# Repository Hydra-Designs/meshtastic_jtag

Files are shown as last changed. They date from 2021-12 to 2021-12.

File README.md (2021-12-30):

# meshtastic_jtag
An easy to assemble JTAG debugging PCB for meshtastic


## Features
- Works with any ESP32 Devkit C compatible board  
- Support for OLED (front) and GPS (back)  
- Compatible with ebyte e22-900m22s LORA module  
- Built in 915MHz monopole antenna   

## Project status
- Gerbers are not tested and schematic has not been reviewed  
- Antenna matching network needs to be optimized  

## Assembly instructions
- Gerber files are in the /gerber/ directory, they are plotted in a format that can be directly uploaded to JLPCB    
- When ordering from JLCPCB don't forget to tick "specify a location" under "remove order number" so that the JLC PCB number is at the PCB back side  
- Assembly should be pretty self-explanatory, minimum hardware requirement is the ESP32 Devkit and the e22-900m22s LORA module with the two decoupling capacitors  
- OLED display goes on the PCB front side  
- NEO6M GPS module goes on the PCB back side  
- The matching network needs fine tuning, for now you should not place C3 and C4 and add a short in place of L1 (small blob of solder)  

## Contributing

Please contribute using [Github Flow](https://guides.github.com/introduction/flow/). Create a branch, add commits, and [open a pull request](https://github.com/PlumRugOfDoom/project-hydra-meshtastic-pcb/compare/). Remember to ```git clone --recursive git@github.com:Hydra-Designs/meshtastic_jtag.git``` or ```git submodule update --init``` since the official espressif KiCAD libs have been included in a submodule.  

## Support

Please [open an issue](https://github.com/PlumRugOfDoom/project-hydra-meshtastic-pcb/issues/new) for support.

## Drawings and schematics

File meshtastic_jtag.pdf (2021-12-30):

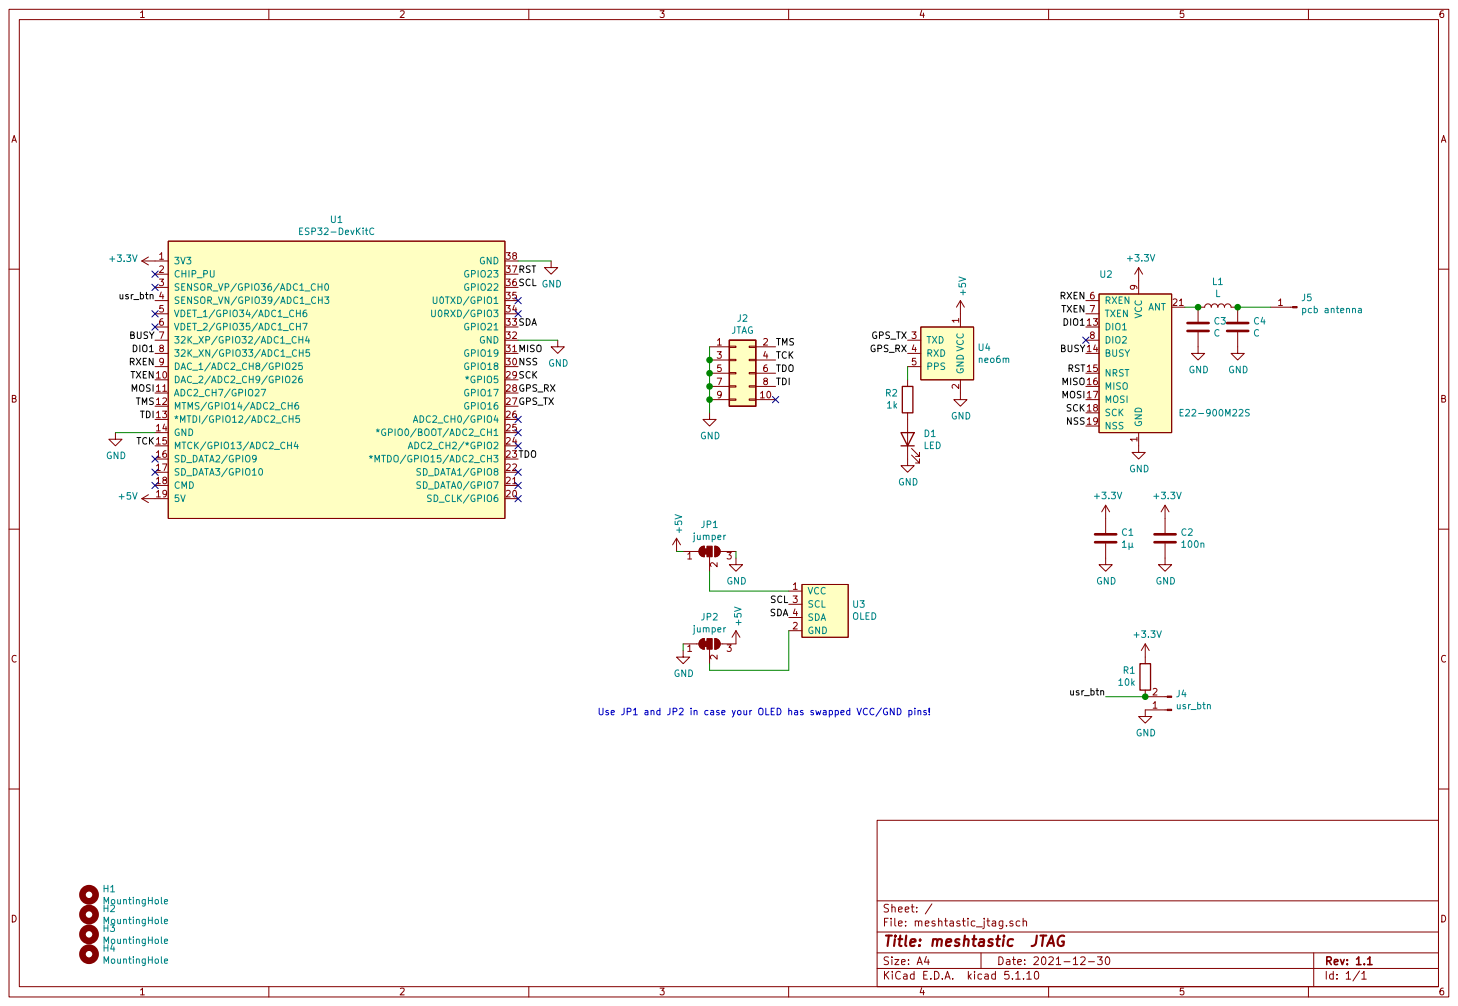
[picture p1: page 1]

SCL NSS RST BUSY DIO1 TXEN

1 DIO1 13 BUSY 14 NRST 15 MISO 16 MOSI 17 SCK 18 NSS 19 ANT RXEN 21

Id: 1/1 Title: meshtastic JTAG

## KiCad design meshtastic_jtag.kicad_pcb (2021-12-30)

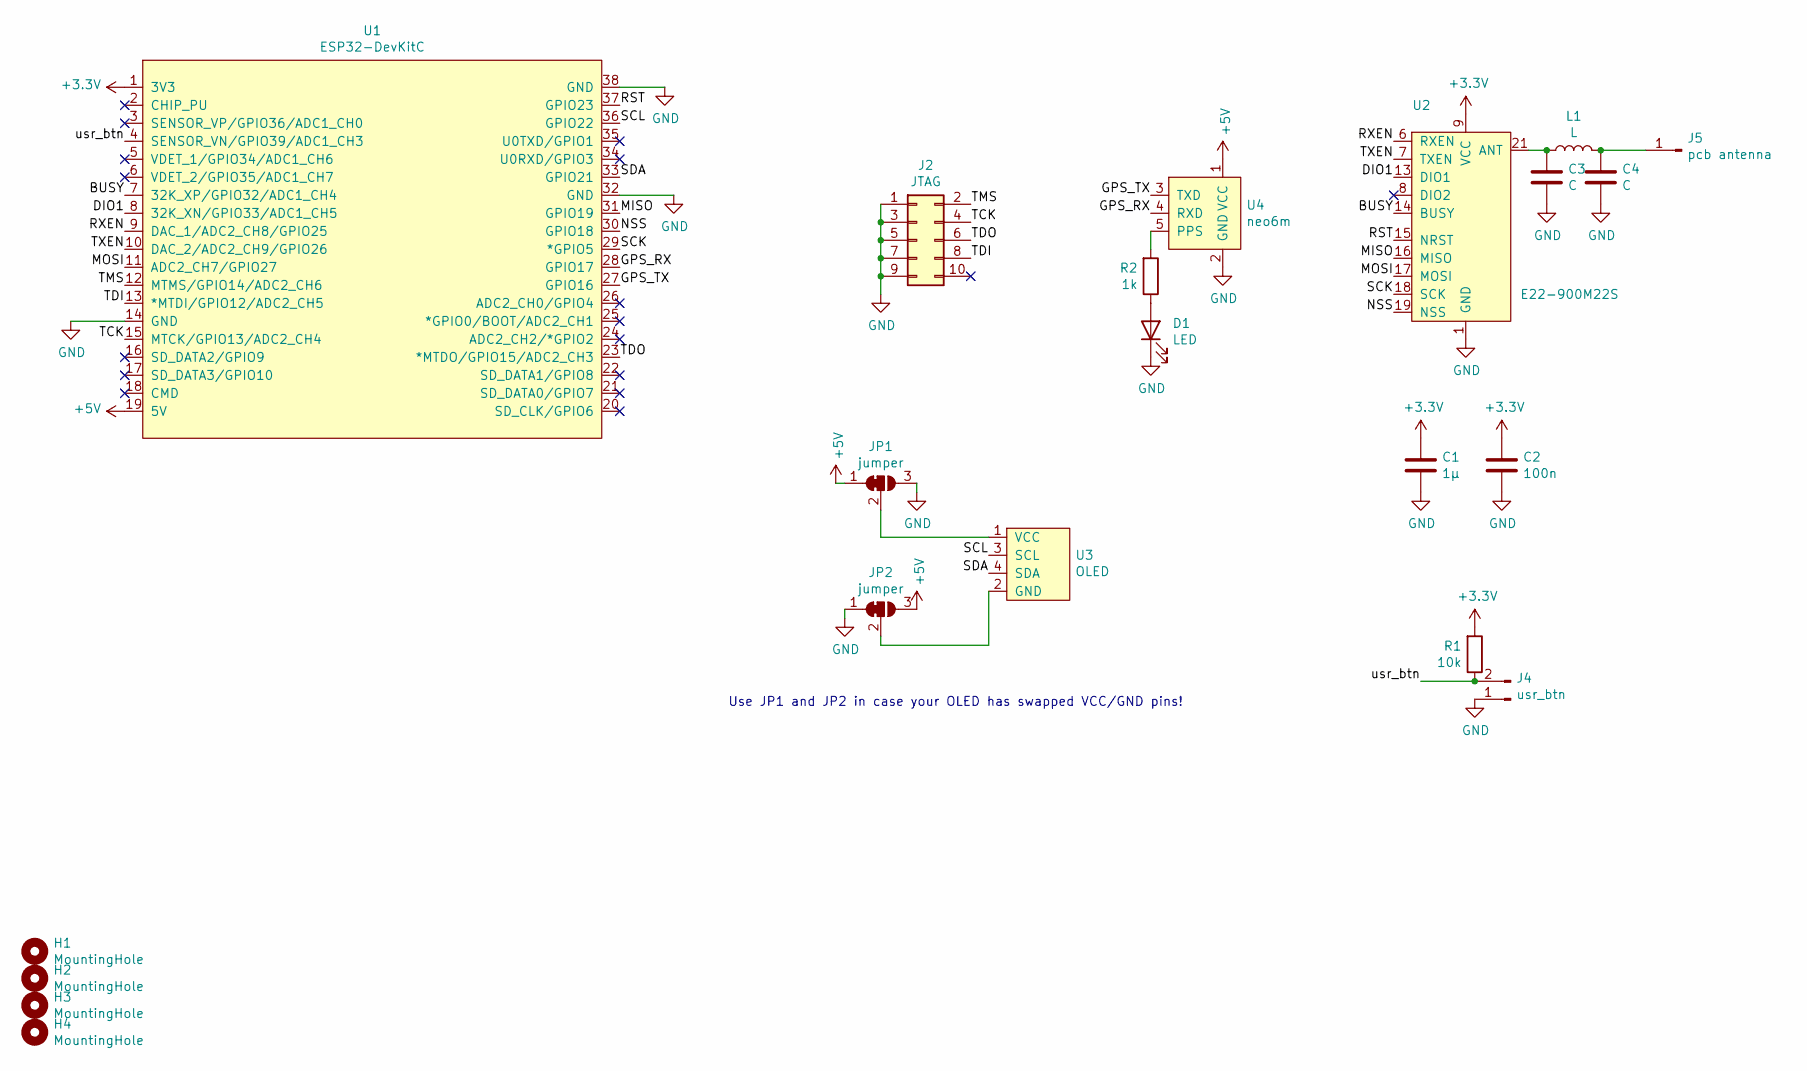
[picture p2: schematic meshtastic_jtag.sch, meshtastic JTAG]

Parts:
C1: 1µ; C_0603_1608Metric
C2: 100n; C_0603_1608Metric
C3, C4: C; C_0402_1005Metric
D1: LED; LED_0805_2012Metric
H1, H2, H3, H4: MountingHole; MountingHole_3.2mm_M3_DIN965
J2: JTAG; PinHeader_2x05_P2.54mm_Vertical
J4: usr_btn; PinHeader_1x02_P2.54mm_Vertical
J5: pcb antenna; TI_DN024
JP1, JP2: jumper; SolderJumper-3_P1.3mm_Bridged12_Pad1.0x1.5mm_NumberLabels
L1: L; C_0402_1005Metric
R1: 10k; R_0805_2012Metric
R2: 1k; R_0805_2012Metric
U1: ESP32-DevKitC
U2: E22-900M22S; e22-900m22s
U3: OLED; oled
U4: neo6m

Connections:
+3V3: C1.1, C2.1, R1.2, U1.1 (3V3), U2.9 (VCC)
+5V: JP1.1 (A), JP2.3 (B), U1.19 (5V), U4.1 (VCC)
/BUSY: U1.7 (32K_XP/GPIO32/ADC1_CH4), U2.14 (BUSY)
/DIO1: U1.8 (32K_XN/GPIO33/ADC1_CH5), U2.13 (DIO1)
/GPS_RX: U1.28 (GPIO17), U4.4 (RXD)
/GPS_TX: U1.27 (GPIO16), U4.3 (TXD)
/MISO: U1.31 (GPIO19), U2.16 (MISO)
/MOSI: U1.11 (ADC2_CH7/GPIO27), U2.17 (MOSI)
/NSS: U1.30 (GPIO18), U2.19 (NSS)
/RST: U1.37 (GPIO23), U2.15 (NRST)
/RXEN: U1.9 (DAC_1/ADC2_CH8/GPIO25), U2.6 (RXEN)
/SCK: U1.29 (*GPIO5), U2.18 (SCK)
/SCL: U1.36 (GPIO22), U3.3 (SCL)
/SDA: U1.33 (GPIO21), U3.4 (SDA)
/TCK: J2.4, U1.15 (MTCK/GPIO13/ADC2_CH4)
/TDI: J2.8, U1.13 (*MTDI/GPIO12/ADC2_CH5)
/TDO: J2.6, U1.23 (*MTDO/GPIO15/ADC2_CH3)
/TMS: J2.2, U1.12 (MTMS/GPIO14/ADC2_CH6)
/TXEN: U1.10 (DAC_2/ADC2_CH9/GPIO26), U2.7 (TXEN)
/usr_btn: J4.2, R1.1, U1.4 (SENSOR_VN/GPIO39/ADC1_CH3)
GND: C1.2, C2.2, C3.2, C4.2, D1.1 (K), J2.1, J2.3, J2.5, J2.7, J2.9, J4.1, JP1.3 (B), JP2.1 (A), U1.14 (GND), U1.32 (GND), U1.38 (GND), U2.1 (GND), U2.2 (GND), U2.3 (GND), U2.4 (GND), U2.5 (GND), U2.10 (GND), U2.11 (GND), U2.12 (GND), U2.20 (GND), U2.22 (GND), U4.2 (GND)
unnamed: C3.1, L1.1, U2.21 (ANT)
unnamed: C4.1, J5.1, L1.2
unnamed: D1.2 (A), R2.1
unnamed: JP1.2 (C), U3.1 (VCC)
unnamed: JP2.2 (C), U3.2 (GND)
unnamed: R2.2, U4.5 (PPS)

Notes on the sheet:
Use JP1 and JP2 in case your OLED has swapped VCC/GND pins!

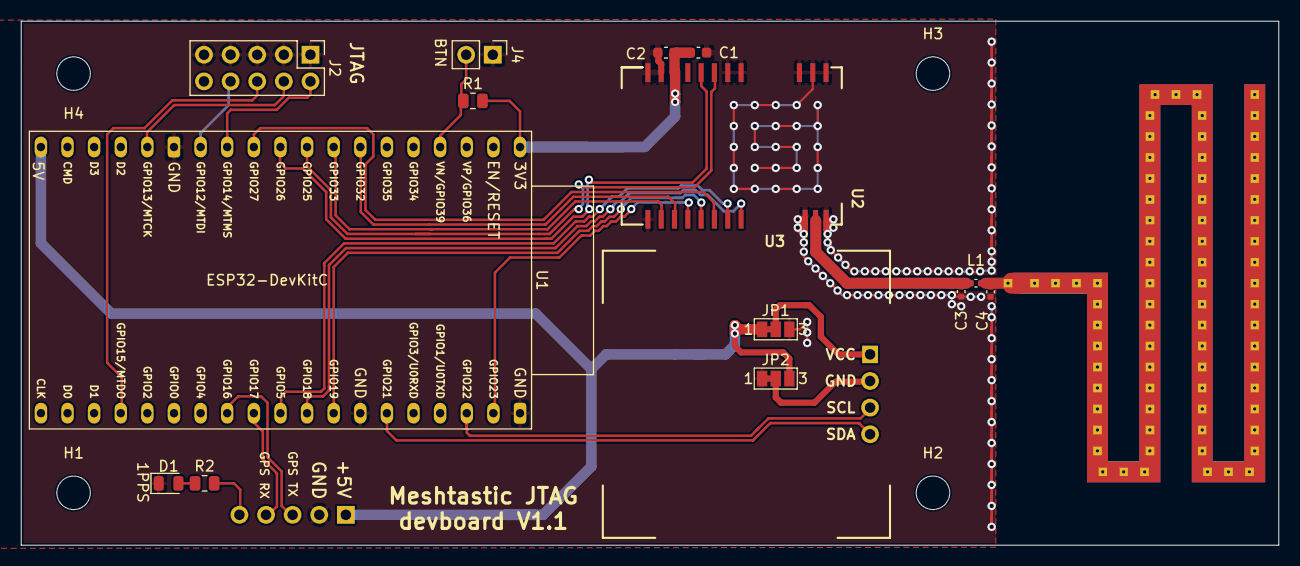
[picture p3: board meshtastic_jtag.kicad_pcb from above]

Board: 2 copper layers, 120.0 x 50.0 mm, 21 parts (1 on the bottom side), 27 nets.

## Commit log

2021-12-29 schematic pdf and gerbers added
    [meshtastic_jtag-B_Cu.gbl, meshtastic_jtag-B_Mask.gbs, meshtastic_jtag-B_SilkS.gbo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]
2021-12-30 bump to V1.1, solder jumpers to swap OLED VCC/GND added
    [meshtastic_jtag-B_Cu.gbl, meshtastic_jtag-B_Mask.gbs, meshtastic_jtag-B_SilkS.gbo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]
